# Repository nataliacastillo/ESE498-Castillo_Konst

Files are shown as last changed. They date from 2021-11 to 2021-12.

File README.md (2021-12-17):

# ESE498-Castillo_Konst
Capstone Project

This is the GitHub page for the 2021 ESE Capstone Design Project conducted by Natalia Castillo and Meagan Konst.<br/>
This project was titled "General Purpose Raspberry Pi HAT".<br/>
The report for this project can be found here: https://docs.google.com/document/d/1kZzHBrRYgLwNy8D9SOFyj6g7AGgq-kcxrAEOaCpLlvI/edit?usp=sharing<br/>
The final presentation slides can be found here: https://docs.google.com/presentation/d/1hZ809Xozr-wZa8N5Z7yGZ-oRJfP1h2XjGNVi-NlqP-0/edit?usp=sharing<br/>
The corresponding website can be found here: sites.wustl.edu/picap2021/<br/>

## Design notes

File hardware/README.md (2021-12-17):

This section includes all of the KiCAD files for our PCB.

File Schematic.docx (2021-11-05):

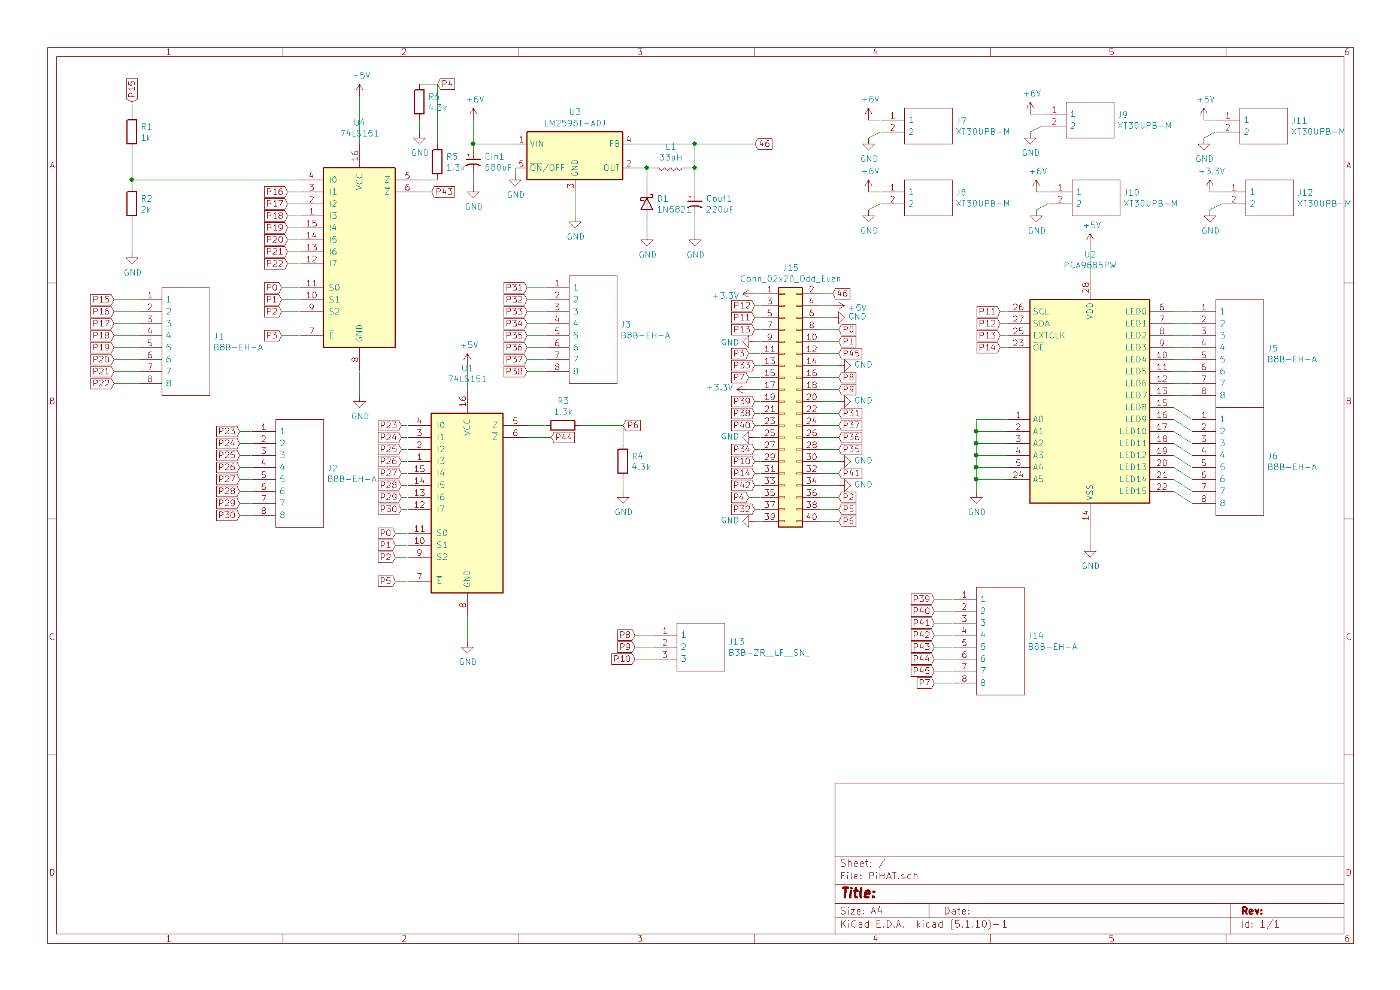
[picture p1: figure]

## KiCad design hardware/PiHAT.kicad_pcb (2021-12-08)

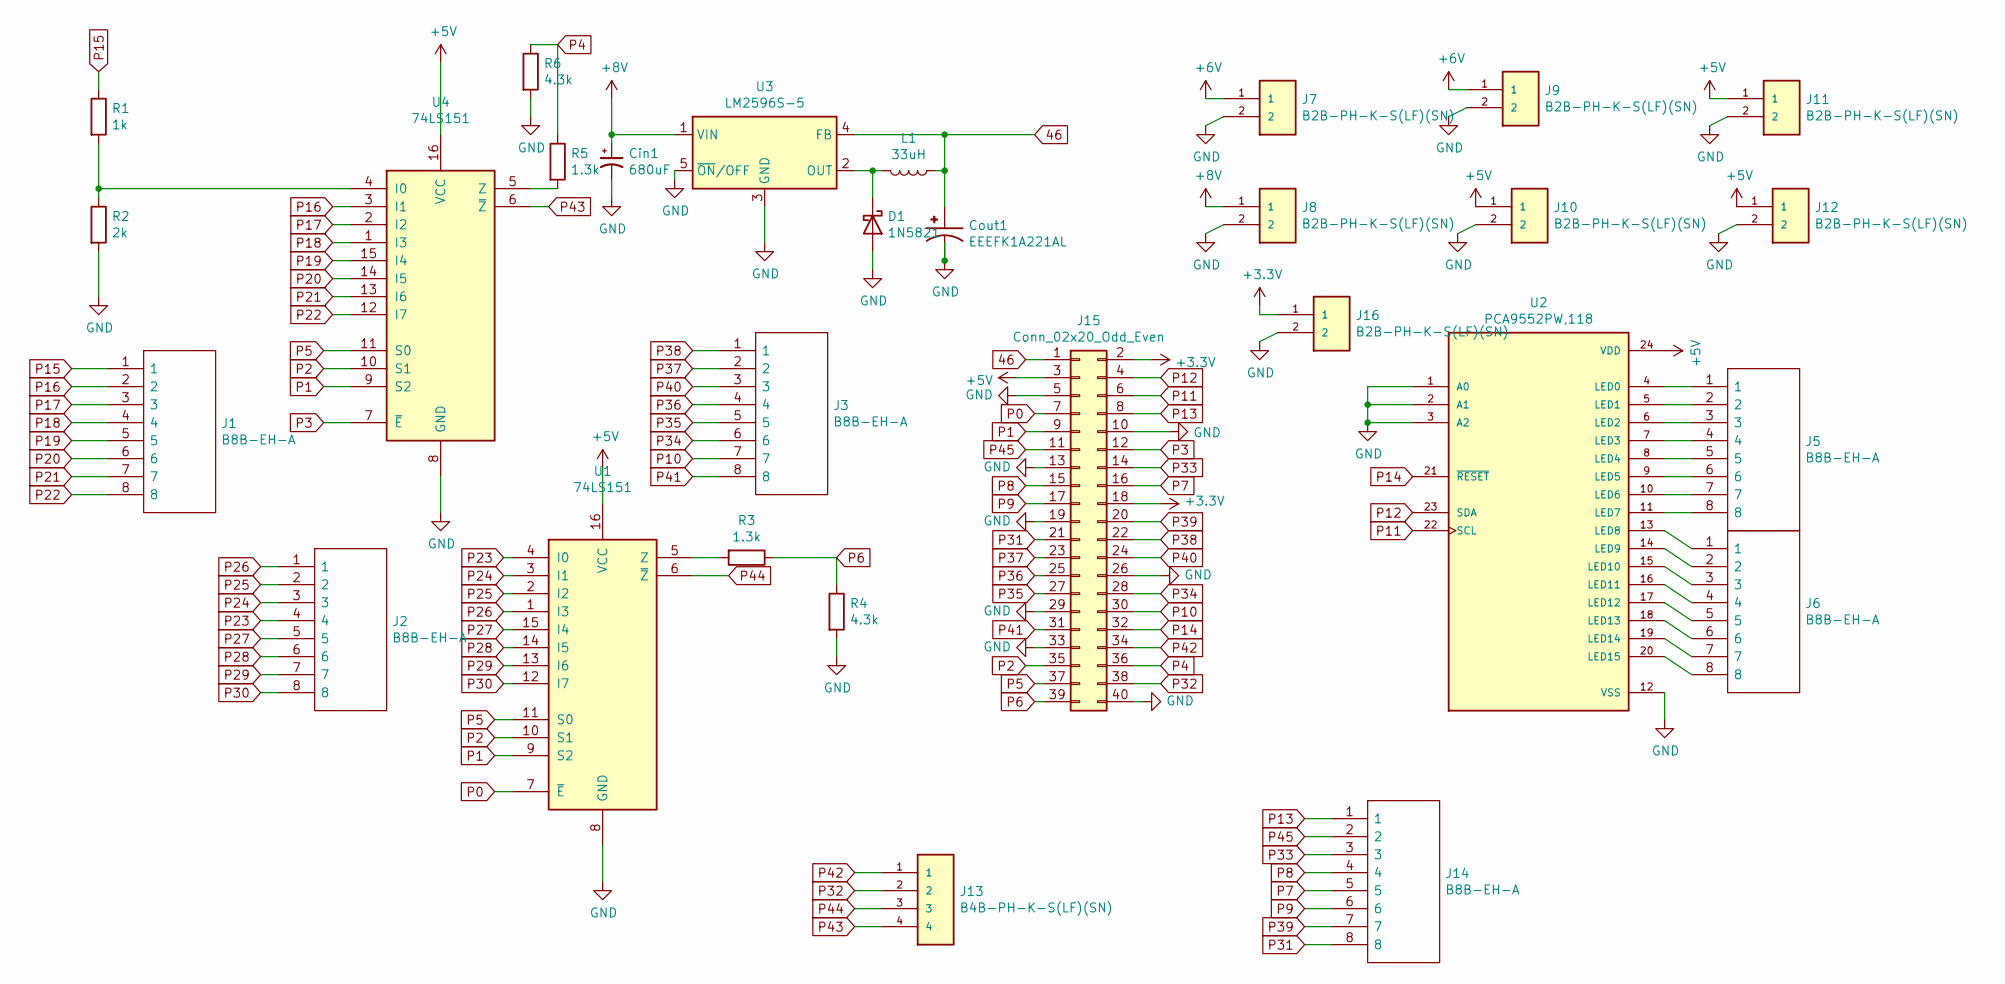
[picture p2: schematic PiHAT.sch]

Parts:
Cin1: 680uF; CP_Elec_10x10.5
Cout1: EEEFK1A221AL; CAP_EEEFK1A221AL; PARTREV 10-Oct-19
D1: 1N5821; D_DO-201AD_P15.24mm_Horizontal
J1, J2, J3, J5, J6, J14: B8B-EH-A; SHDR8W64P0X250_1X8_2250X380X600P; Manufacturer_Part_Number B8B-EH-A
J7, J8, J9, J10, J11, J12, J16: B2B-PH-K-S(LF)(SN); JST_B2B-PH-K-S(LF)(SN); PARTREV N/A; DIGI-KEY_PART_NUMBER 455-1704-ND
J13: B4B-PH-K-S(LF)(SN); JST_B4B-PH-K-S(LF)(SN)
J15: Conn_02x20_Odd_Even; Pin_Header_Straight_2x20
L1: 33uH; L_12x12mm_H8mm
R1: 1k; R_0402_1005Metric
R2: 2k; R_0402_1005Metric
R3, R5: 1.3k; R_0402_1005Metric
R4, R6: 4.3k; R_0402_1005Metric
U1, U4: 74LS151; SOIC127P600X175-16N
U2: PCA9552PW,118; SOP65P640X110-24N; PARTREV 05
U3: LM2596S-5; TO-263-5_TabPin3

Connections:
46: Cout1.1, J15.1, L1.1, U3.4 (FB)
+3V3: J15.2, J15.18, J16.1
+5V: J10.1, J11.1, J12.1, J15.3, U1.16 (VCC), U2.24 (VDD), U4.16 (VCC)
+6V: J7.1, J9.1
+8V: Cin1.1, J8.1, U3.1 (VIN)
GND: Cin1.2, Cout1.2, D1.2 (A), J7.2, J8.2, J9.2, J10.2, J11.2, J12.2, J15.5, J15.10, J15.13, J15.19, J15.26, J15.29, J15.33, J15.40, J16.2, R2.2, R4.2, R6.2, U1.8 (GND), U2.1 (A0), U2.2 (A1), U2.3 (A2), U2.12 (VSS), U3.3 (GND), U3.5 (~ON~/OFF), U4.8 (GND)
unnamed: D1.1 (K), L1.2, U3.2 (OUT)
unnamed: J5.1, U2.4 (LED0)
unnamed: J5.2, U2.5 (LED1)
unnamed: J5.3, U2.6 (LED2)
unnamed: J5.4, U2.7 (LED3)
unnamed: J5.5, U2.8 (LED4)
unnamed: J5.6, U2.9 (LED5)
unnamed: J5.7, U2.10 (LED6)
unnamed: J5.8, U2.11 (LED7)
unnamed: J6.1, U2.13 (LED8)
unnamed: J6.2, U2.14 (LED9)
unnamed: J6.3, U2.15 (LED10)
unnamed: J6.4, U2.16 (LED11)
unnamed: J6.5, U2.17 (LED12)
unnamed: J6.6, U2.18 (LED13)
unnamed: J6.7, U2.19 (LED14)
unnamed: J6.8, U2.20 (LED15)
unnamed: R1.2, R2.1, U4.4 (I0)
unnamed: R3.2, U1.5 (Z)
unnamed: R5.2, U4.5 (Z)
P0: J15.7, U1.7 (~E)
P1: J15.9, U1.9 (S2), U4.9 (S2)
P2: J15.35, U1.10 (S1), U4.10 (S1)
P3: J15.12, U4.7 (~E)
P4: J15.36, R5.1, R6.1
P5: J15.37, U1.11 (S0), U4.11 (S0)
P6: J15.39, R3.1, R4.1
P7: J14.5, J15.16
P8: J14.4, J15.15
P9: J14.6, J15.17
P10: J3.7, J15.30
P11: J15.6, U2.22 (SCL)
P12: J15.4, U2.23 (SDA)
P13: J14.1, J15.8
P14: J15.32, U2.21 (~RESET)
P15: J1.1, R1.1
P16: J1.2, U4.3 (I1)
P17: J1.3, U4.2 (I2)
P18: J1.4, U4.1 (I3)
P19: J1.5, U4.15 (I4)
P20: J1.6, U4.14 (I5)
P21: J1.7, U4.13 (I6)
P22: J1.8, U4.12 (I7)
P23: J2.4, U1.4 (I0)
P24: J2.3, U1.3 (I1)
P25: J2.2, U1.2 (I2)
P26: J2.1, U1.1 (I3)
P27: J2.5, U1.15 (I4)
P28: J2.6, U1.14 (I5)
P29: J2.7, U1.13 (I6)
P30: J2.8, U1.12 (I7)
P31: J14.8, J15.21
P32: J13.2, J15.38
P33: J14.3, J15.14
P34: J3.6, J15.28
P35: J3.5, J15.27
P36: J3.4, J15.25
P37: J3.2, J15.23
P38: J3.1, J15.22
P39: J14.7, J15.20
P40: J3.3, J15.24
P41: J3.8, J15.31
P42: J13.1, J15.34
P43: J13.4, U4.6 (~Z)
P44: J13.3, U1.6 (~Z)
P45: J14.2, J15.11

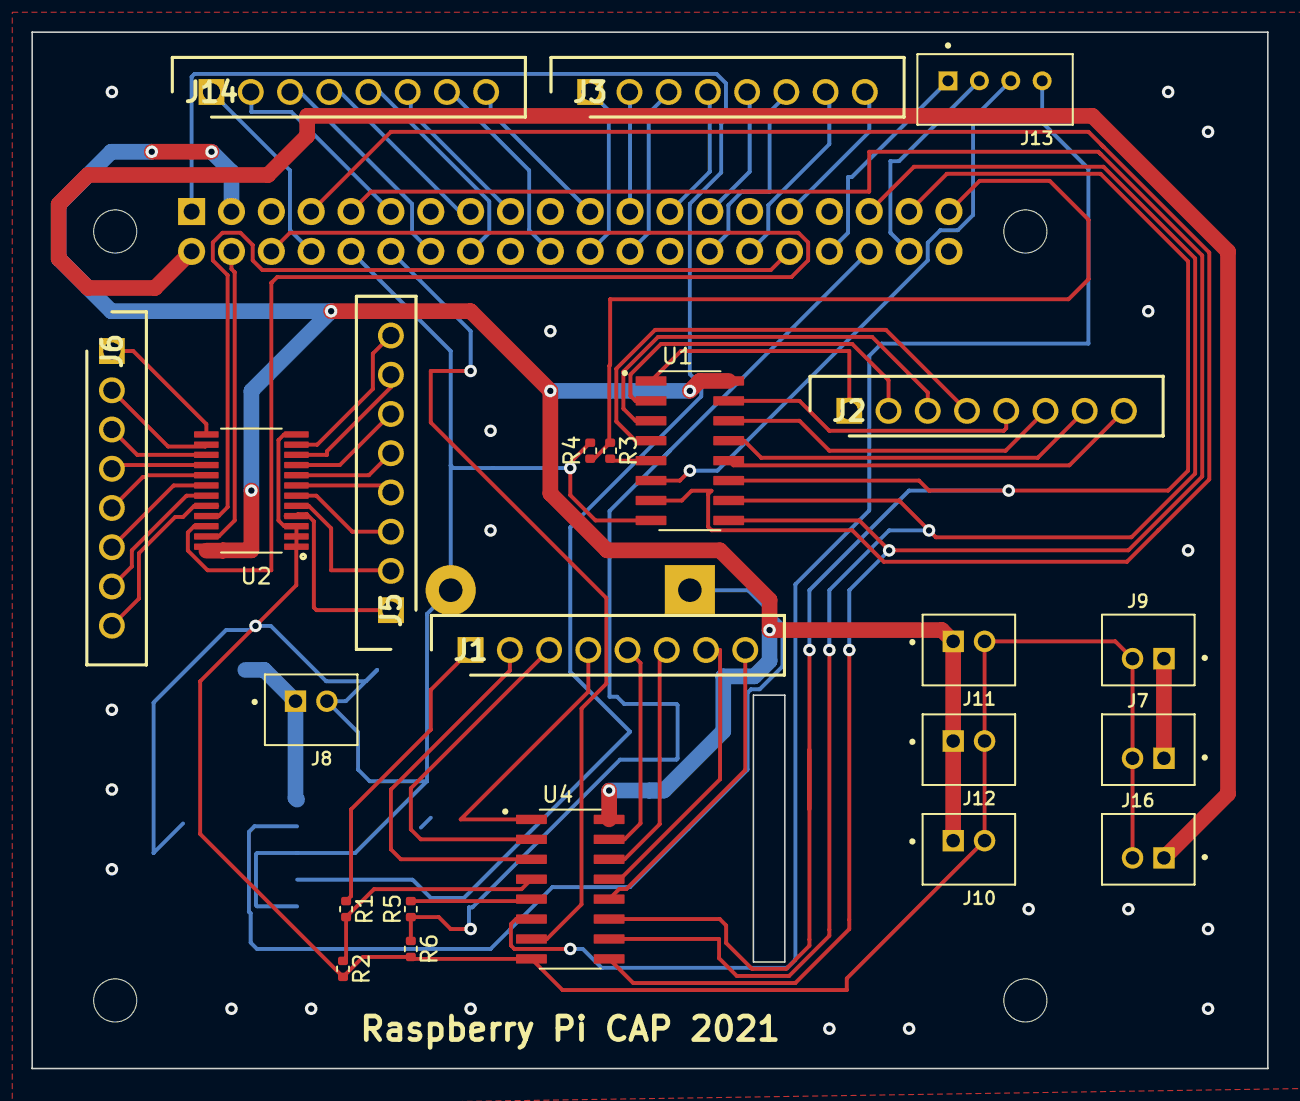
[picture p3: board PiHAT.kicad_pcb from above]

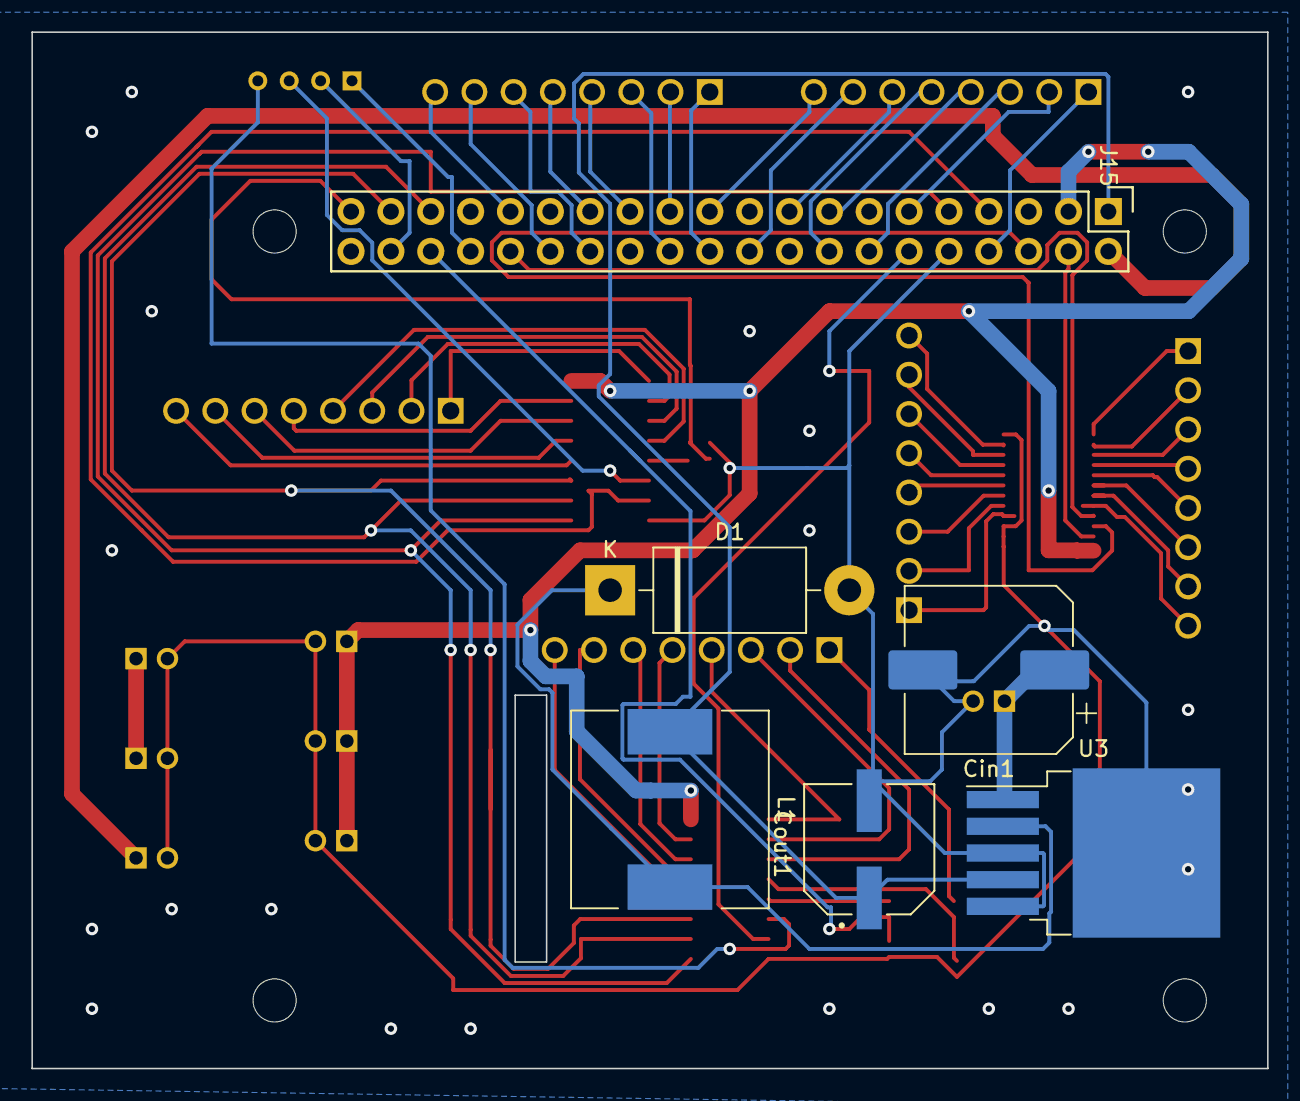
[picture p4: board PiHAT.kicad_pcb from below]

Board: 2 copper layers, 78.7 x 66.0 mm, 29 parts (6 on the bottom side), 72 nets.

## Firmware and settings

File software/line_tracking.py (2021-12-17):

import rospy
import time
import RPi.GPIO as GPIO
import numpy as np
from std_msgs.msg import Int32MultiArray
from std_msgs.msg import Int16


GPIO.setmode(GPIO.BOARD)
# GPIO.setwarnings(False)

# Pin Assignments
# MUX Output
#FRONT_MUX = 35
#BACK_MUX = 40

# MUX ADDRESS BITS
# MSB = 10
# MID = 36
# LSB = 38

# MUX Propogation Delay
# PROP_TIME = 43e-9

# Address Assignments
# LT1 = 1
# LT2 = 2
# LT3 = 3
# LT4 = 4
# LT5 = 5

# Sensor PINs
F1_A = 23
F2_A = 26
F3_A = 29
F4_A = 32
F5_A = 33
B1_A = 7
B2_A = 12
B3_A = 13
B4_A = 16
B5_A = 15

# Setting Sensor PINs to Inputs
GPIO.setup(F1_A, GPIO.IN)
GPIO.setup(F2_A, GPIO.IN)
GPIO.setup(F3_A, GPIO.IN)
GPIO.setup(F4_A, GPIO.IN)
GPIO.setup(F5_A, GPIO.IN)
GPIO.setup(B1_A, GPIO.IN)
GPIO.setup(B2_A, GPIO.IN)
GPIO.setup(B3_A, GPIO.IN)
GPIO.setup(B4_A, GPIO.IN)
GPIO.setup(B5_A, GPIO.IN)

# MUX Address Global Variable
#address = 0

# Setting MUX OUTPUT Signals to Inputs
# GPIO.setup(FRONT_MUX, GPIO.IN)
# GPIO.setup(BACK_MUX, GPIO.IN)

# Setting MUX ADDRESS BITS to Outputs
# GPIO.setup(MSB, GPIO.OUT)
# GPIO.setup(MID, GPIO.OUT)
# GPIO.setup(LSB, GPIO.OUT)

rospy.init_node('line_node', anonymous=True)
message_publisher = rospy.Publisher(
   'line_values', Int32MultiArray, queue_size = 1)
rate = rospy.Rate(15)


def publish():
   sensors = readSensors()
   rospy.loginfo(sensors)
   message_publisher.publish(sensors)
   rate.sleep()

#def callback(data):
#   global address
#   address = data.data

#def receiver():
#   rospy.Subscriber('address', Int16, callback)

def readSensors():
   # Assignments to Global Variables require the
   # global var_name line to function properly
   #global F1, F2, F3, F4, F5, B1, B2, B3, B4, B5
   #if address == LT1:
   #   GPIO.output(MSB, 0)
   #   GPIO.output(MID, 0)
   #   GPIO.output(LSB, 1)
   #   time.sleep(PROP_TIME)
   #   F1 = GPIO.input(FRONT_MUX)
   #   B1 = GPIO.input(BACK_MUX)
   #elif address == LT2:
   #   GPIO.output(MSB, 0)
   #   GPIO.output(MID, 1)
   #   GPIO.output(LSB, 0)
   #   time.sleep(PROP_TIME)
   #   F2 = GPIO.input(FRONT_MUX)
   #   B2 = GPIO.input(BACK_MUX)
   #elif address == LT3:
   #   GPIO.output(MSB, 0)
   #   GPIO.output(MID, 1)
   #   GPIO.output(LSB, 1)
   #   time.sleep(PROP_TIME)
   #   F3 = GPIO.input(FRONT_MUX)
   #   B3 = GPIO.input(BACK_MUX)
   #elif address == LT4:
   #   GPIO.output(MSB, 1)
   #   GPIO.output(MID, 0)
   #   GPIO.output(LSB, 0)
   #   time.sleep(PROP_TIME)
   #   F4 = GPIO.input(FRONT_MUX)
   #   B4 = GPIO.input(BACK_MUX)
   #elif address == LT5:
   #   GPIO.output(MSB, 1)
   #   GPIO.output(MID, 0)
   #   GPIO.output(LSB, 1)
   #   time.sleep(PROP_TIME)
   #   F5 = GPIO.input(FRONT_MUX)
   #   B5 = GPIO.input(BACK_MUX)
   
   F1 = GPIO.input(F1_A)
   F2 = GPIO.input(F2_A)
   F3 = GPIO.input(F3_A)
   F4 = GPIO.input(F4_A)
   F5 = GPIO.input(F5_A)
   B1 = GPIO.input(B1_A)
   B2 = GPIO.input(B2_A)
   B3 = GPIO.input(B3_A)
   B4 = GPIO.input(B4_A)
   B5 = GPIO.input(B5_A)
   
   signals = Int32MultiArray()
   data = np.array([
      F1, F2, F3, F4, F5, B1, B2, B3, B4, B5
      ])
   signals.data = data
   return signals

if __name__ == '__main__':
   # receiver()
   while not rospy.is_shutdown():
      try:
         publish()
      except rospy.ROSInterruptException:
         pass

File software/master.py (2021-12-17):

import rospy
import time
import numpy as np
import signal
from std_msgs.msg import Int32MultiArray
from std_msgs.msg import Int16
from std_msgs.msg import Bool
from std_msgs.msg import Float32

# Constants
NOTHING = 0
LEFT = 1
RIGHT = 2
END = 3
# Number of cm away from an object where we need to stop
STOP_VALUE = 167
# Number of seconds it takes to turn
TURN_TIME = 5
# FORWARD SPEED
FORWARD = 15

# Global Variables
#angle = 90
#turning = 0
#end = 0
#speed = 15
#take_picture = 0


rospy.init_node('master', anonymous=True)
picture_publisher = rospy.Publisher(
   'take_picture', Bool, queue_size=1)
motor_publisher = rospy.Publisher(
   'speed', Int16, queue_size=1)
steering_publisher = rospy.Publisher(
   'angle', Int16, queue_size=1)
#address_publisher = rospy.Publisher(
#   'address', Int16, queue_size=1)
rate = rospy.Rate(15)

#signal.signal(signal.SIGINT, signal.default_int_handler)
#def sig_handler(signal, frame):
 #  angle = 90
  # publish_angle()
  # speed = 0
  # publish_speed()
  # exit()


# Creates Signal Handler for CNTL + C keyboard entry
#signal.signal(signal.SIGINT, sig_handler)


def publish_picture():
   picture = Bool()
   picture.data = take_picture
   log_string = f"MASTER SENT TAKE PICTURE: {picture.data}"
   rospy.loginfo(log_string)
   picture_publisher.publish(picture)
   rate.sleep()


def publish_speed():
   global speed
   if end:
      speed = 0
   data = Int16()
   data.data = speed
   log_info = f"SPEED: {data.data}"
   rospy.loginfo(log_info)
   motor_publisher.publish(data)
   rate.sleep()


def publish_angle():
   global angle
   if end:
      angle = 90
   data = Int16()
   data.data = angle
   log_info = f"ANGLE: {data.data}"
   rospy.loginfo(log_info)
   steering_publisher.publish(data)
   rate.sleep()

#def publish_address():
#   data = Int16()
#   for i in range(6):
#      data.data = i
#      log_string = f"ADDRESS: {data.data}"
#      rospy.loginfo(log_string)
#      address_publisher.publish(data)
#      rate.sleep()


def turn_callback(data):
   global angle, turning, end, speed
   dA = data.data
   if dA == LEFT or dA == RIGHT:
      turning = 1
   elif dA == END:
      end = 1
   caller_id = rospy.get_caller_id()
   turn_string = "DON'T"
   if dA == LEFT:
      turn_string = "LEFT"
      angle = 160
      speed = 15
      time.sleep(TURN_TIME)
      speed = 0
      angle = 90
      turning = 0
   elif dA == RIGHT:
      turn_string = "RIGHT"
      angle = 20
      speed = 15
      time.sleep(TURN_TIME)
      speed = 0
      angle = 90
      turning = 0
   elif dA == END:
      turn_string = "END"
      speed = 0
   log_string = f"MASTER RECEIVED TURN: {turn_string}"
   rospy.loginfo(log_string)


def line_callback(data):
   global angle
   caller_id = rospy.get_caller_id()
   dA = data.data
   log_string = f"ID: {caller_id} LINE DATA: {dA}"
   rospy.loginfo(log_string)

   # Priority Check
   if turning:
      return

   # Sensor Decoding
   # (F1, F2, F3, F4, F5, B1, B2, B3, B4, B5)
   # 1 is Leftmost, 5 is Rightmost

   # Ideal Tracking
   if dA == (0, 1, 1, 1, 0, 0, 1, 1, 1, 0):
      angle = 90
      return
   if dA[0] == 1:
      # Front Leftmost Sensor Covered -> Turn Left
      angle = 120
      return
   if dA[4] == 1:
      # Front Rightmost Sensor Covered -> Turn Right
      angle = 60
      return
   if dA[5] == 1:
      # Back Leftmost Sensor Covered -> Turn Left
      angle = 120
      return
   if dA[9] == 1:
      # Back Rightmost Sensor Covered -> Turn Right
      angle = 60
      return


def distance_callback(data):
   global speed, take_picture
   caller_id = rospy.get_caller_id()
   log_string = f"MASTER RECEIVED DISTANCE: {data.data} cm"
   rospy.loginfo(log_string)

   # Priority Check
   if turning or end:
      return
   if data.data <= STOP_VALUE:
      take_picture = 1
      speed = 0
   else:
      speed = FORWARD


def receivers():
   rospy.Subscriber('turn', Int16, turn_callback)
   rospy.Subscriber('line_values', Int32MultiArray, line_callback)
   rospy.Subscriber('distances', Float32, distance_callback)


if __name__ == '__main__':
   global turning, angle, speed, take_picture, end
   angle = 90
   speed = FORWARD
   take_picture = 0
   end = 0
   turning = 0
   receivers()
   while not rospy.is_shutdown():
      try:
         publish_picture()
         publish_speed()
         publish_angle()
         #publish_address()
         #rospy.spin()
      except rospy.ROSInterruptException:
         pass
      #except KeyboardInterrupt:
      #   end = 1
         #angle = 90
         #publish_angle()
         #speed = 0
         #publish_speed()
         #exit()
